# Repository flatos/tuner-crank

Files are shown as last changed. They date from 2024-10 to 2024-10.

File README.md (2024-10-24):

# A Crank-Style Knob for an Antenna Tuner's Rotary Inductor

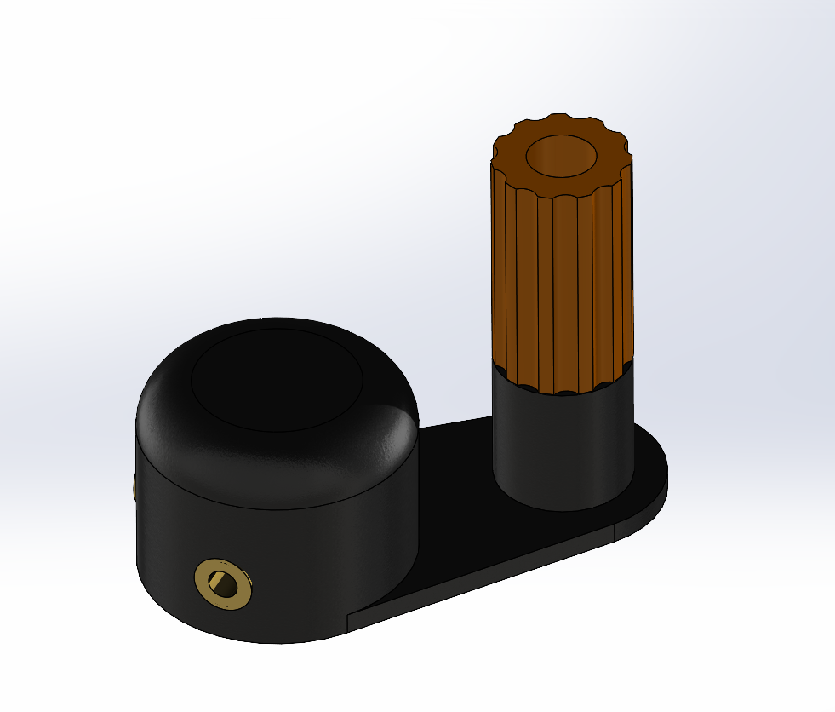
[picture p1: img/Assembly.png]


I have an MFJ-989C antenna tuner...the user experience would be improved if it had a "crank"-style knob for rotary inductor control, like many newer tuners.
This repository contain STL models and SolidWorks files for a crank suitable for any control with a 1/4" shaft.

## Assembly

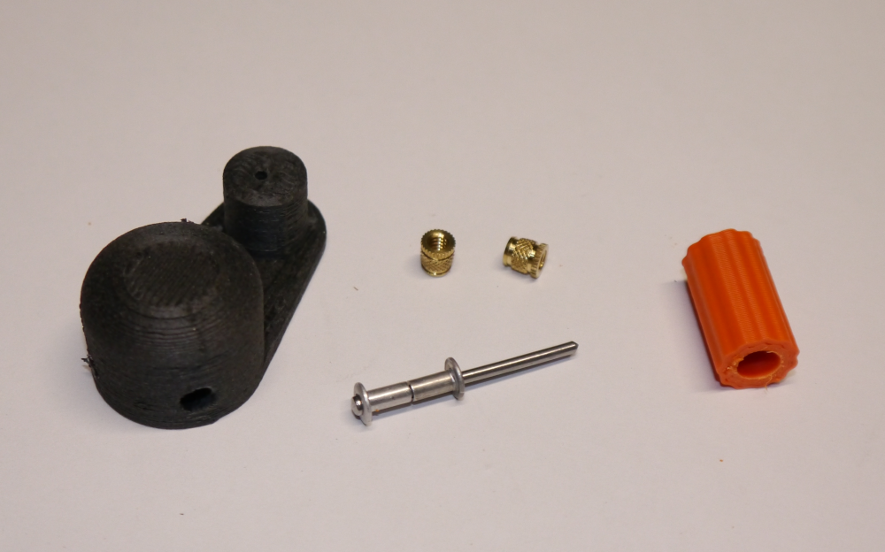
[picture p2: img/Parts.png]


Print the STL files in the `/models` directory. I used `eSun ePA-CF` filament (carbon-fiber nylon) for the crank and ASA for the knob,
but presumably anything would work.

Use the parts from a couple of pop rivets to assemble the pin for the knob as shown.

Clean up the holes in the parts with a drill (0.25" for the shaft and interior of knob, 0.191" or so for the inserts, 0.080" for the pin).

Install the 6-32 brass inserts with a hot soldering iron.

Assemble and epoxy the pin in place on the underside. Use a bit of paper or similar to space the knob away from the crank until the glue cures to ensure that it spins freely.

<br/>
Installed on the tuner, with the original knob for comparison:
<br/>
<br/>

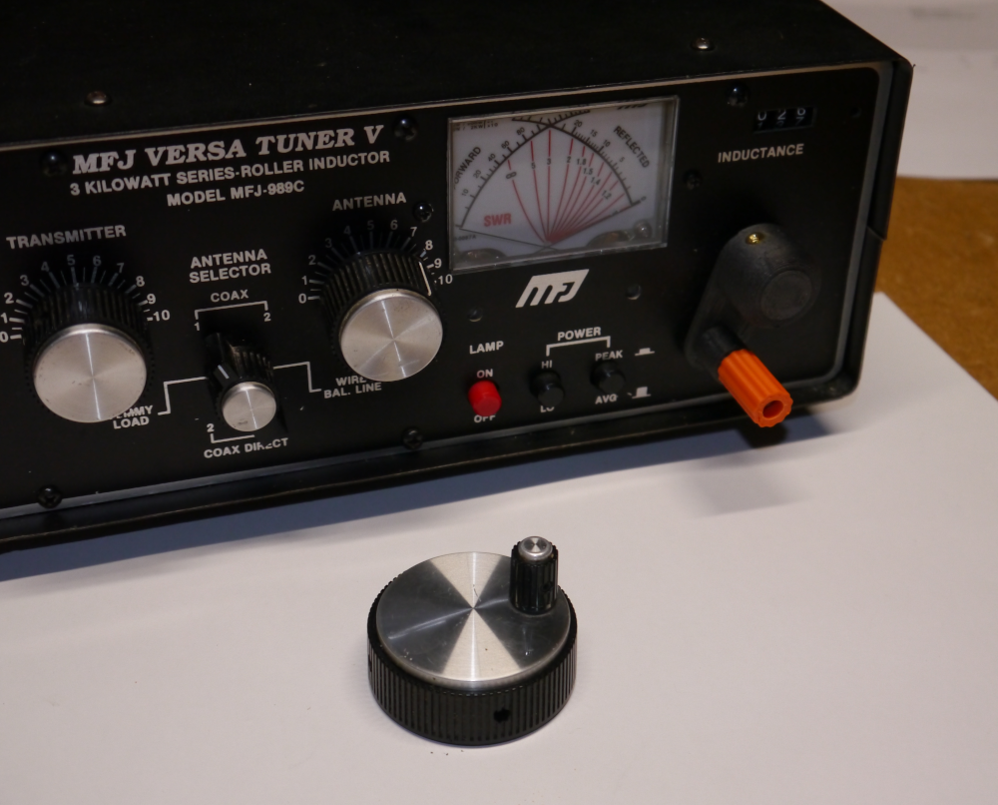
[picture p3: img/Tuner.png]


## Disclaimer
You access to and use the contents of this site at your own risk.\
The author assumes no responsibility or liability for any errors or omissions in the content of this site.\
The information and models provided on this site are provided in good faith, however we make no representation  or warranty of any kind,
express or implied, regarding the accuracy, adequacy,  validity, reliability, or completeness of any information on the site.

## Contact
ac8p@proton.me

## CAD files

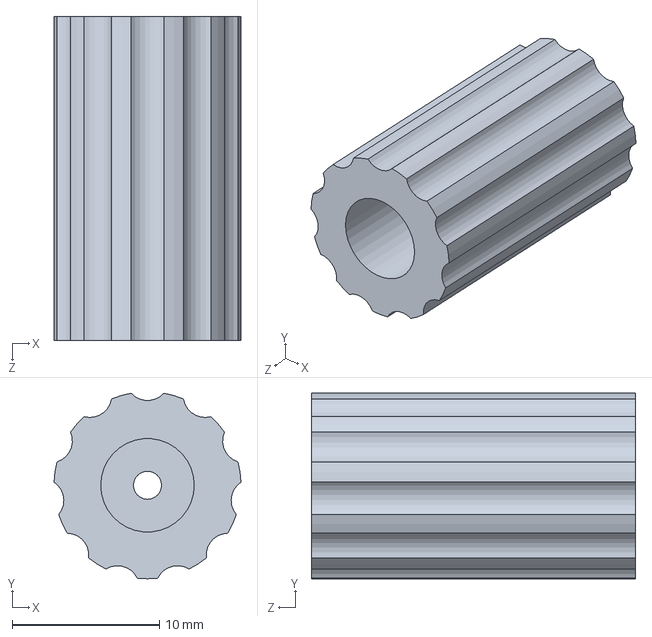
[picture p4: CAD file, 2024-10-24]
models/Knob.SLDPRT
12.7 x 12.6 x 22.0 mm

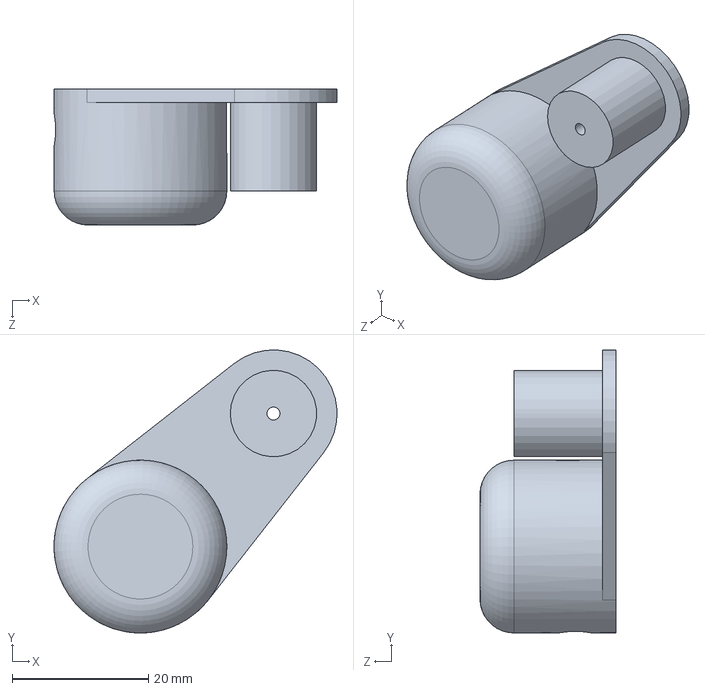
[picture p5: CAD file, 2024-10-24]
models/Crank.SLDPRT
41.6 x 41.6 x 20.0 mm

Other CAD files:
models/Crank.STL
models/Knob.STL
